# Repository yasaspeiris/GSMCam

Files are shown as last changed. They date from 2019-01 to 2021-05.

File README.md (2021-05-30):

# GSMCam
A Python program to determine the Grams per Square Meter of a Fabric using hardware accelerated Image Processing
(Also contains source code, design files and PCB schematics for cartesian slider system used to move the camera across fabrics.)

cover1_97ebsi5cop

Conventional method of fabric GSM measurement involves cutting a small round piece of fabric with an area of 0.01 square centimeters and measuring its weight using a precision balance.This project was aimed to replace this conventional method with an optical based one. Currently the scope of the project is limited to single light color (white) fabrics with a plain, twill weave. (Algorithm can also be applied to knit fabrics with a considerable accuracy as well)

For anyone looking to implement a hardware accelerated application with minimal development and debugging time, PYNQ is a great option. Currently PYNQ supports several boards including the Ultra96. The computer vision library for PYNQ provides several overlays for accelerating OpenCV functions in hardware. Currently Filter2D and dilation operations are supported. 

The following flow diagram depicts the stages in the GSM Determination process.

sssddd

The GUI is made using Flask, and can be used to calibrate and view results.



### Complete Instructions : 
https://www.hackster.io/yasaspeiris/fabric-gsm-determination-using-ultra96-pynq-6c5499

### Contributors : 

Pasindu Liyanage

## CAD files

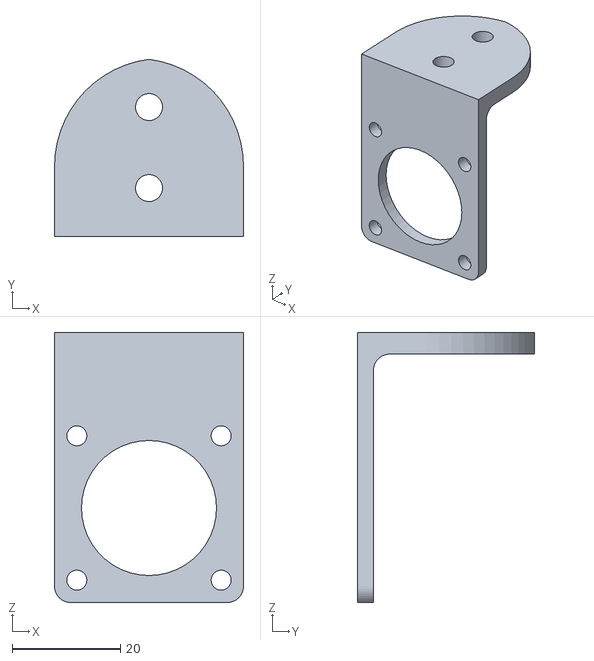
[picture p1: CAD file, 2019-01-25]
slider/slider_parts/ychainholder.STL
35.0 x 32.8 x 50.0

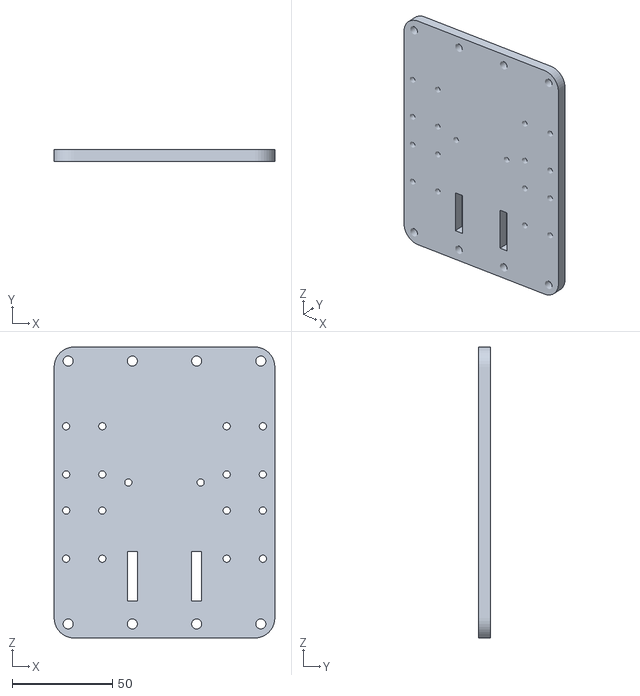
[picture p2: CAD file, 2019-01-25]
slider/slider_parts/ygantry.STL
110.0 x 6.00 x 145.0

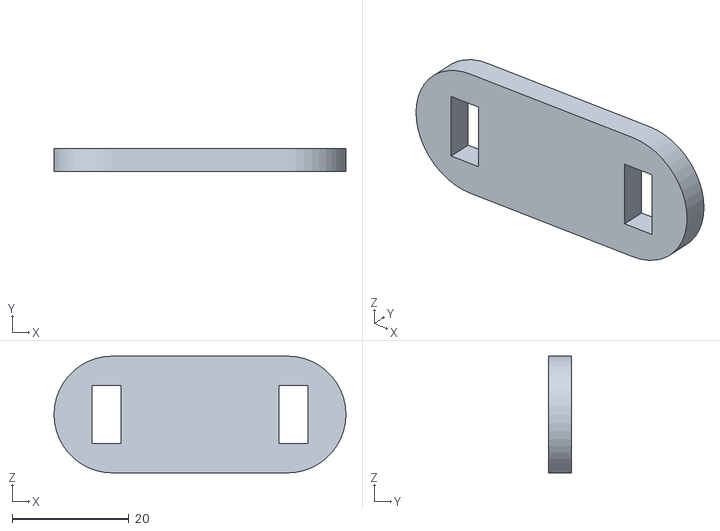
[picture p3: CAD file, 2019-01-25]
slider/slider_parts/zmotorspacer.STL
50.0 x 4.00 x 20.0

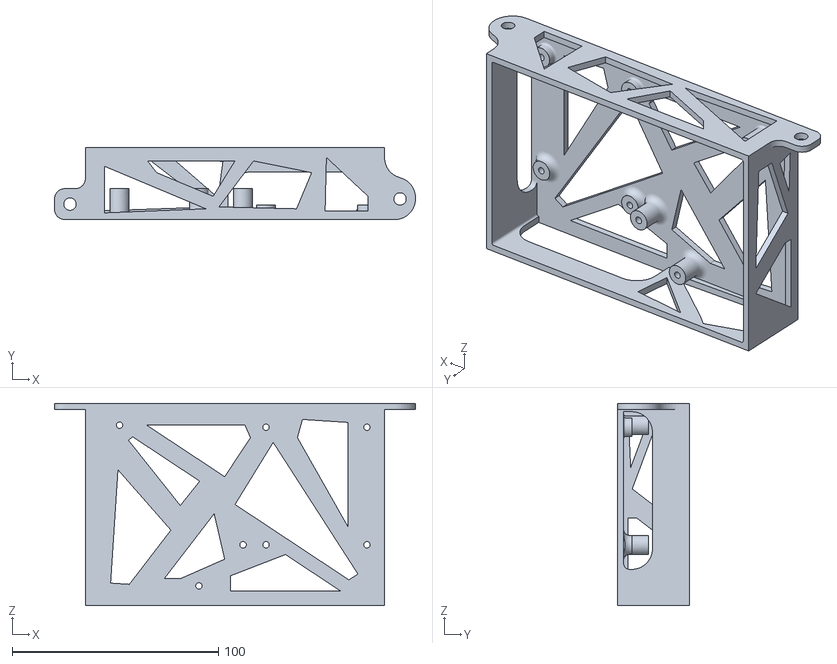
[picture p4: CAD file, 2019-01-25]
slider/slider_parts/cover.STL
175.0 x 35.0 x 98.0

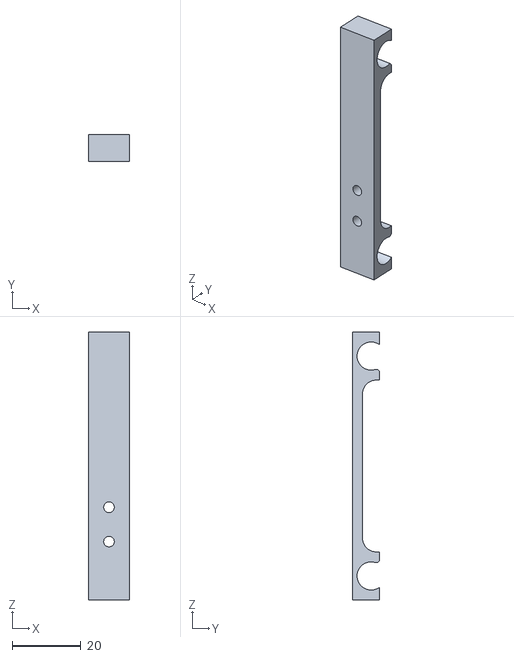
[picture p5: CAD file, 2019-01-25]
slider/slider_parts/switchholder_z.STL
12.0 x 8.00 x 78.0

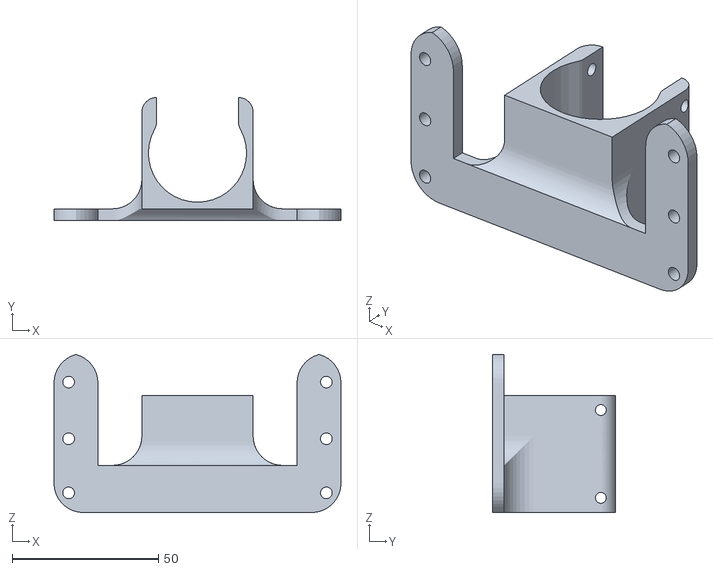
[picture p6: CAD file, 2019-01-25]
slider/slider_parts/camholder.STL
98.0 x 42.0 x 54.0

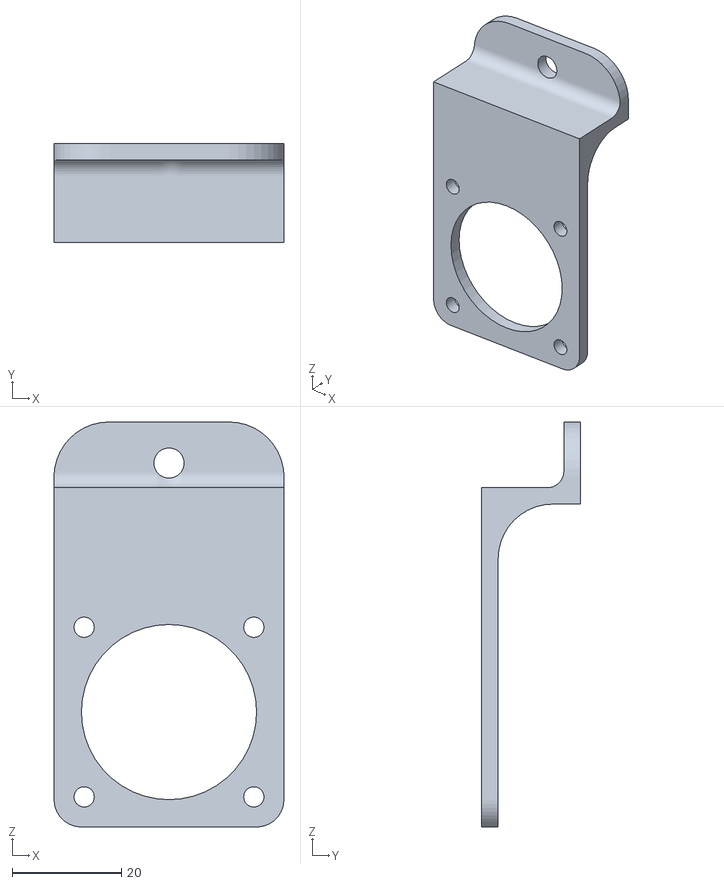
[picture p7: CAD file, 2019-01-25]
slider/slider_parts/chainsupportmotor.STL
42.0 x 18.0 x 74.0

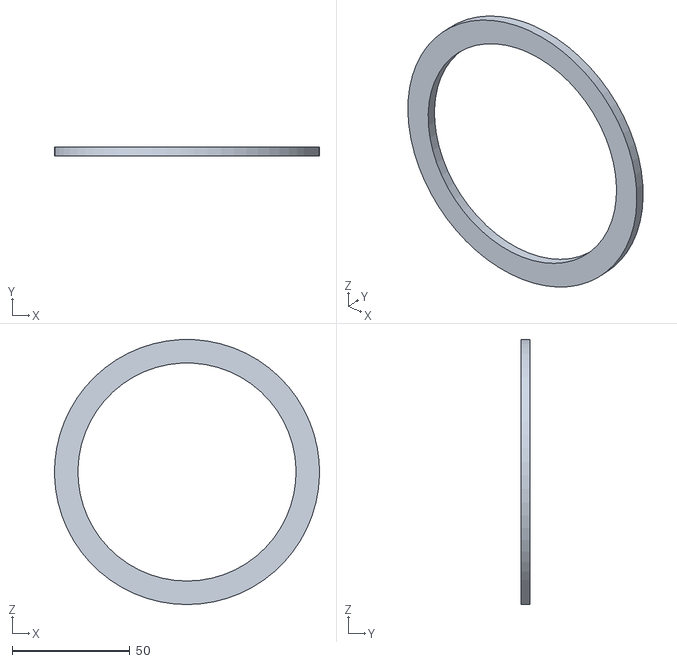
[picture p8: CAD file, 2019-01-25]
slider/slider_parts/fabriccutter.STL
112.8 x 4.00 x 112.8

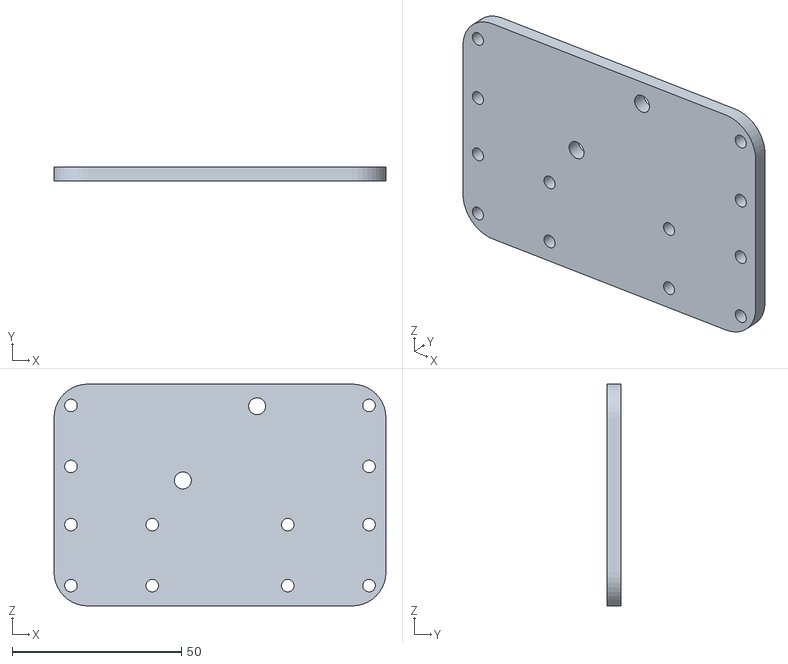
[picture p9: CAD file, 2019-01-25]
slider/slider_parts/zgantry.STL
98.0 x 4.00 x 65.5

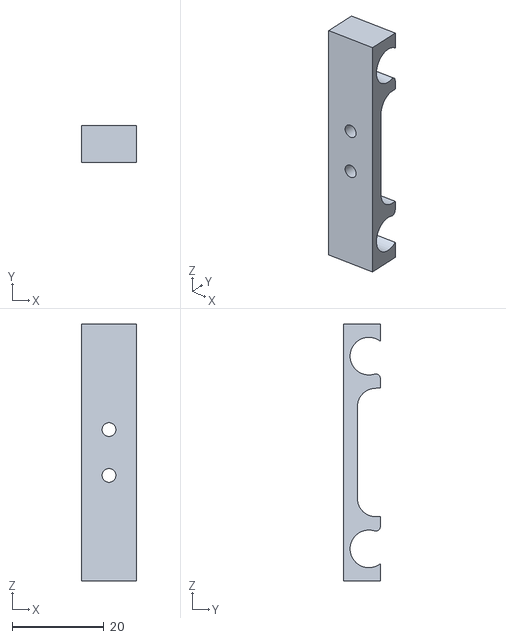
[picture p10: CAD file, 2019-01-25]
slider/slider_parts/switchhold.STL
12.0 x 8.00 x 56.0

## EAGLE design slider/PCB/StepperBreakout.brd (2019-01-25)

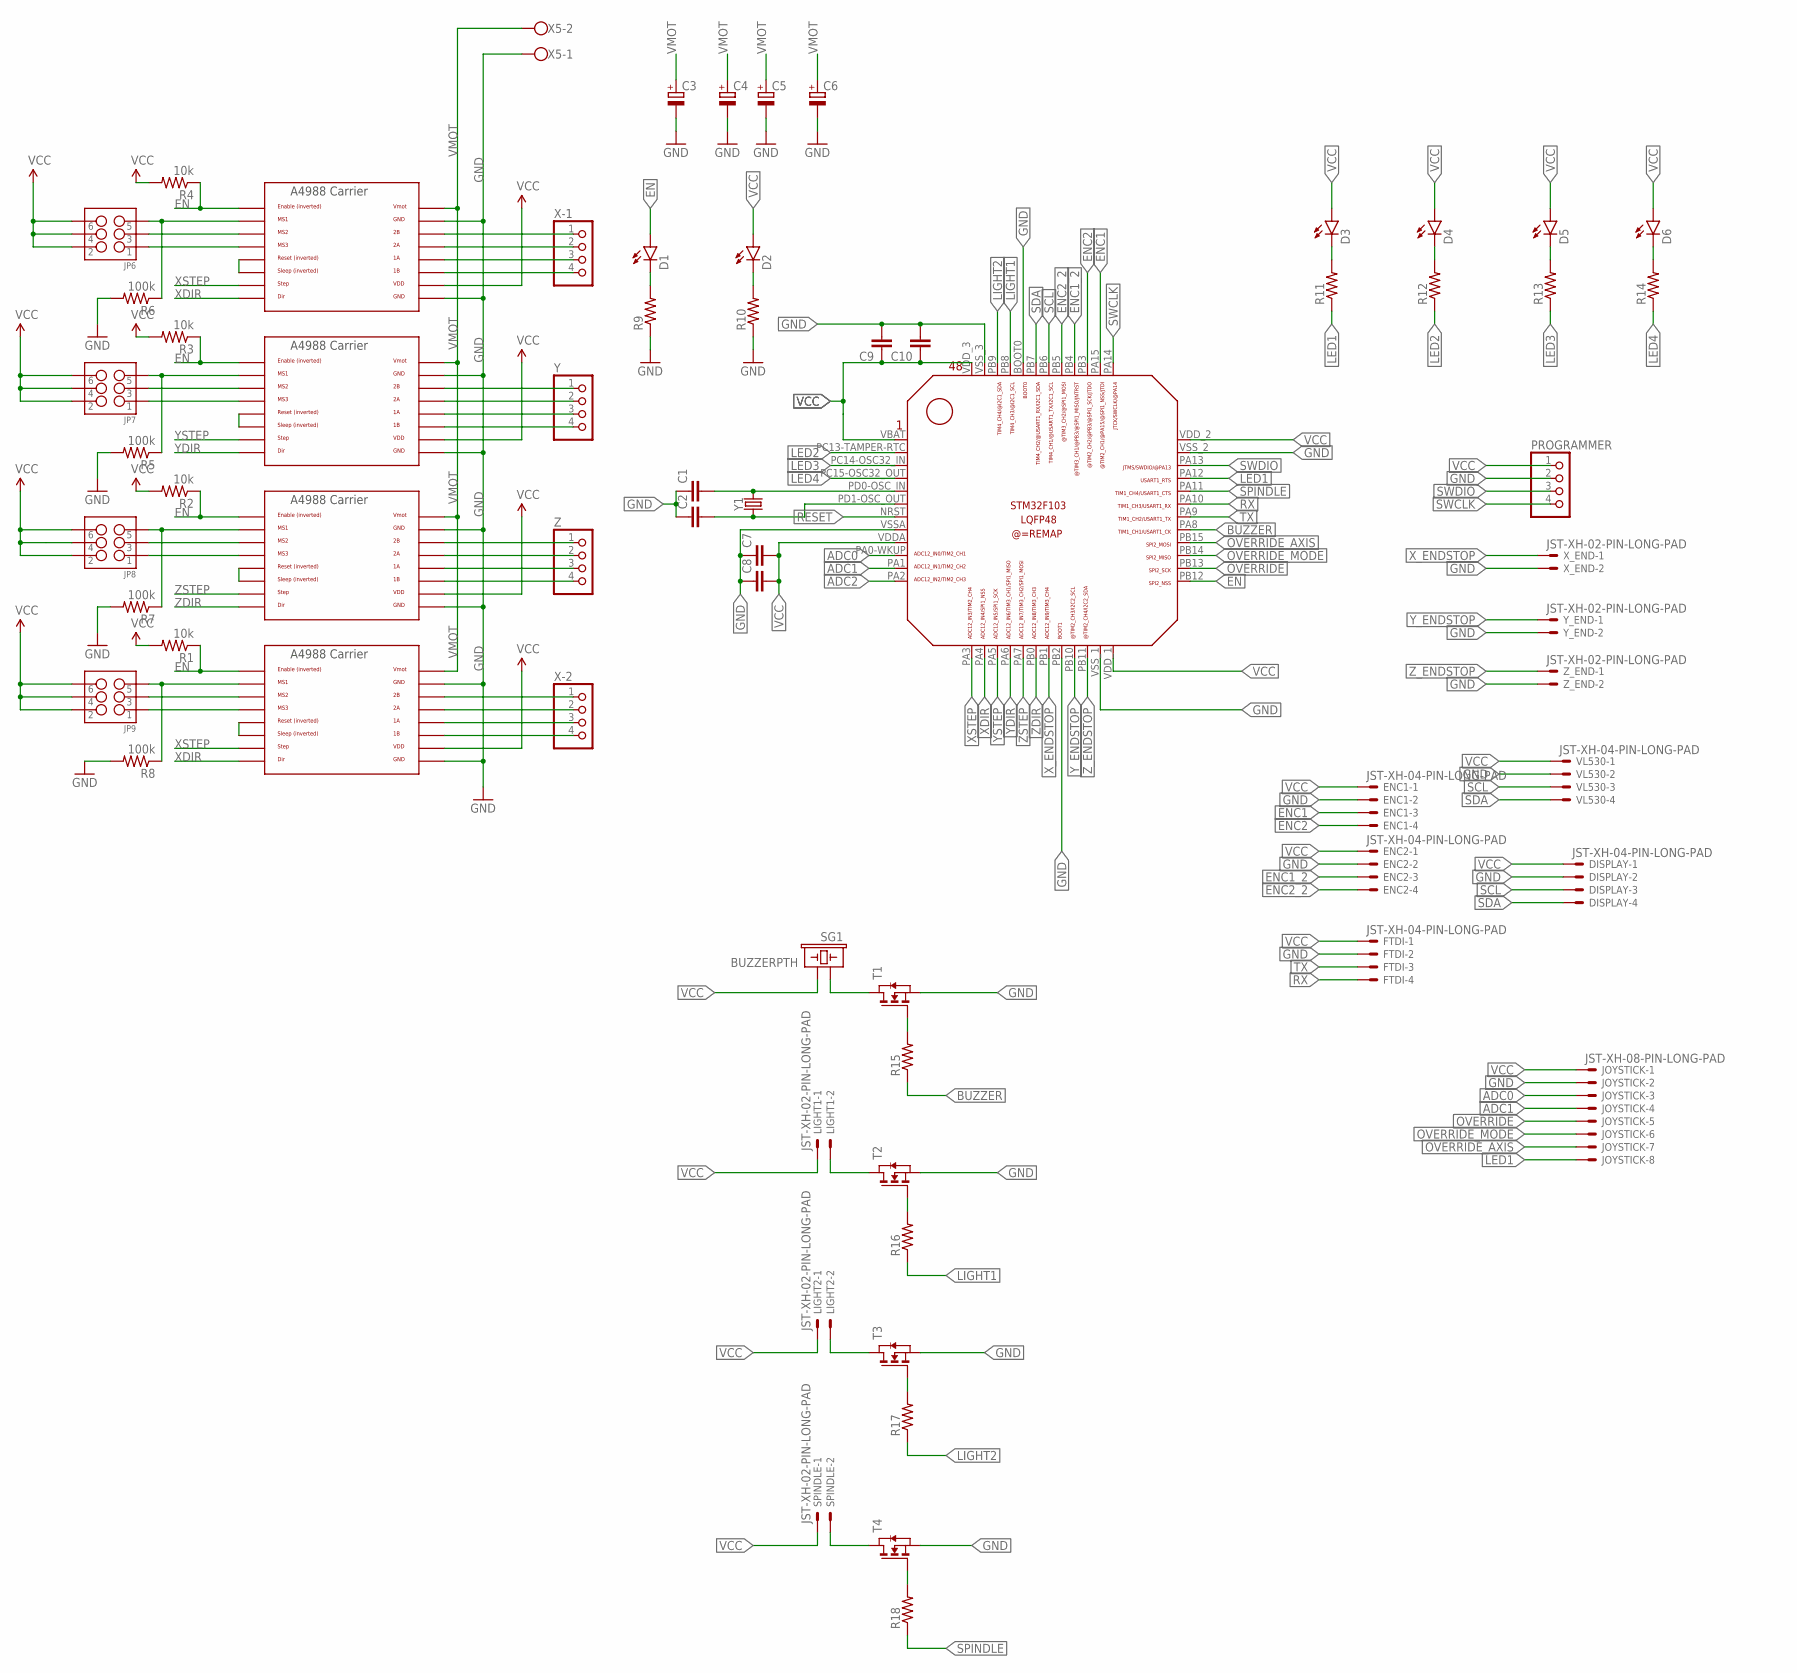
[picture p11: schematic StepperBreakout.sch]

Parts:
C1, C2, C7, C8, C9, C10: C-EUC0805; C0805
C3, C4, C5, C6: CPOL-EUE5-8.5; E5-8,5
D1, D2, D3, D4, D5, D6: LED0603; LED-0603
DISPLAY: JST-XH-04-PIN-LONG-PAD; JST-XH-04-PACKAGE-LONG-PAD
ENC1, ENC2: JST-XH-04-PIN-LONG-PAD; JST-XH-04-PACKAGE-LONG-PAD
FTDI: JST-XH-04-PIN-LONG-PAD; JST-XH-04-PACKAGE-LONG-PAD
JOYSTICK: JST-XH-08-PIN-LONG-PAD; JST-XH-08-PACKAGE-LONG-PAD
JP6, JP7, JP8, JP9: M03X2NO_SILK; 2X3-NS
LIGHT1, LIGHT2: JST-XH-02-PIN-LONG-PAD; JST-XH-02-PACKAGE-LONG-PAD
PROGRAMMER: PINHD-1X4; 1X04
R1, R2, R3, R4: 10k; 0805
R5, R6, R7, R8: 100k; 0805
R9, R10, R11, R12, R13, R14, R15, R16, R17, R18: RESISTOR0805-RES; 0805
SG1: BUZZERPTH; BUZZER-12MM
SPINDLE: JST-XH-02-PIN-LONG-PAD; JST-XH-02-PACKAGE-LONG-PAD
T1, T2, T3, T4: NMOSSOT23; SOT-23
U$1, U$2, U$3, U$4: POLOLU_A4983CARRIER; A4988BREAKOUT
U$5: STM32F103_LQFP48
VL530: JST-XH-04-PIN-LONG-PAD; JST-XH-04-PACKAGE-LONG-PAD
X5: W237-102
X-1, X-2: PINHD-1X4; 1X04
X_END: JST-XH-02-PIN-LONG-PAD; JST-XH-02-PACKAGE-LONG-PAD
Y: PINHD-1X4; 1X04
Y1: CRYSTALPTH-HC49UV; HC49U
Y_END: JST-XH-02-PIN-LONG-PAD; JST-XH-02-PACKAGE-LONG-PAD
Z: PINHD-1X4; 1X04
Z_END: JST-XH-02-PIN-LONG-PAD; JST-XH-02-PACKAGE-LONG-PAD

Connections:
ADC0: JOYSTICK.3, U$5.PA0-WKUP
ADC1: JOYSTICK.4, U$5.PA1
ADC2: U$5.PA2
BUZZER: R15.1, U$5.PA8
EN: D1.A, R1.1, R2.1, R3.1, R4.1, U$1.EN, U$2.EN, U$3.EN, U$4.EN, U$5.PB12
ENC1: ENC1.3, U$5.PA15
ENC1_2: ENC2.3, U$5.PB4
ENC2: ENC1.4, U$5.PB3
ENC2_2: ENC2.4, U$5.PB5
GND: C1.1, C2.1, C3.-, C4.-, C5.-, C6.-, C7.1, C8.1, C9.2, C10.2, DISPLAY.2, ENC1.2, ENC2.2, FTDI.2, JOYSTICK.2, PROGRAMMER.2, R5.2, R6.2, R7.2, R8.2, R9.1, R10.1, T1.2 (S), T2.2 (S), T3.2 (S), T4.2 (S), U$1.GND, U$1.GND@0 (GND), U$2.GND, U$2.GND@0 (GND), U$3.GND, U$3.GND@0 (GND), U$4.GND, U$4.GND@0 (GND), U$5.BOOT0, U$5.PB2, U$5.VSSA, U$5.VSS_1, U$5.VSS_2, U$5.VSS_3, VL530.2, X5.1, X_END.2, Y_END.2, Z_END.2
LED1: JOYSTICK.8, R11.1, U$5.PA12
LED2: R12.1, U$5.PC13-TAMPER-RTC
LED3: R13.1, U$5.PC14-OSC32_IN
LED4: R14.1, U$5.PC15-OSC32_OUT (PC15-OSC_OUT)
LIGHT1: R16.1, U$5.PB8
LIGHT2: R17.1, U$5.PB9
unnamed: U$3.1B, Y.4
unnamed: U$3.1A, Y.3
unnamed: U$3.2A, Y.2
unnamed: U$3.2B, Y.1
unnamed: U$1.2B, Z.1
unnamed: U$1.2A, Z.2
unnamed: U$1.1A, Z.3
unnamed: U$1.1B, Z.4
unnamed: U$2.2B, X-2.1
unnamed: U$2.2A, X-2.2
unnamed: U$2.1A, X-2.3
unnamed: U$2.1B, X-2.4
unnamed: U$4.2B, X-1.1
unnamed: U$4.2A, X-1.2
unnamed: U$4.1A, X-1.3
unnamed: U$4.1B, X-1.4
unnamed: JP6.5, R6.1, U$4.MS1
unnamed: JP6.3, U$4.MS2
unnamed: JP6.1, U$4.MS3
unnamed: JP7.5, R5.1, U$3.MS1
unnamed: JP7.3, U$3.MS2
unnamed: JP7.1, U$3.MS3
unnamed: JP8.5, R7.1, U$1.MS1
unnamed: JP8.3, U$1.MS2
unnamed: JP8.1, U$1.MS3
unnamed: JP9.5, R8.1, U$2.MS1
unnamed: JP9.3, U$2.MS2
unnamed: JP9.1, U$2.MS3
unnamed: C1.2, U$5.PD0-OSC_IN, Y1.2
unnamed: D1.C, R9.2
unnamed: D2.C, R10.2
unnamed: C2.2, U$5.PD1-OSC_OUT, Y1.1
unnamed: U$2.RST, U$2.SLP (SLEEP)
unnamed: U$1.RST, U$1.SLP (SLEEP)
unnamed: U$3.RST, U$3.SLP (SLEEP)
unnamed: U$4.RST, U$4.SLP (SLEEP)
unnamed: D3.C, R11.2
unnamed: D4.C, R12.2
unnamed: D5.C, R13.2
unnamed: D6.C, R14.2
unnamed: SG1.+ (1), T1.1 (D)
unnamed: R15.2, T1.3 (G)
unnamed: LIGHT1.2, T2.1 (D)
unnamed: R16.2, T2.3 (G)
unnamed: LIGHT2.2, T3.1 (D)
unnamed: R17.2, T3.3 (G)
unnamed: SPINDLE.2, T4.1 (D)
unnamed: R18.2, T4.3 (G)
OVERRIDE: JOYSTICK.5, U$5.PB13
OVERRIDE_AXIS: JOYSTICK.7, U$5.PB15
OVERRIDE_MODE: JOYSTICK.6, U$5.PB14
RESET: U$5.NRST
RX: FTDI.4, U$5.PA10
SCL: DISPLAY.3, U$5.PB6, VL530.3
SDA: DISPLAY.4, U$5.PB7, VL530.4
SPINDLE: R18.1, U$5.PA11
SWCLK: PROGRAMMER.4, U$5.PA14
SWDIO: PROGRAMMER.3, U$5.PA13
TX: FTDI.3, U$5.PA9
VCC: C7.2, C8.2, C9.1, C10.1, D2.A, D3.A, D4.A, D5.A, D6.A, DISPLAY.1, ENC1.1, ENC2.1, FTDI.1, JOYSTICK.1, JP6.2, JP6.4, JP6.6, JP7.2, JP7.4, JP7.6, JP8.2, JP8.4, JP8.6, JP9.2, JP9.4, JP9.6, LIGHT1.1, LIGHT2.1, PROGRAMMER.1, R1.2, R2.2, R3.2, R4.2, SG1.- (2), SPINDLE.1, U$1.VDD, U$2.VDD, U$3.VDD, U$4.VDD, U$5.VBAT, U$5.VDDA, U$5.VDD_1, U$5.VDD_2, U$5.VDD_3, VL530.1
VMOT: C3.+, C4.+, C5.+, C6.+, U$1.VMOT, U$2.VMOT, U$3.VMOT, U$4.VMOT, X5.2
XDIR: U$2.DIR, U$4.DIR, U$5.PA4
XSTEP: U$2.STEP, U$4.STEP, U$5.PA3
X_ENDSTOP: U$5.PB1, X_END.1
YDIR: U$3.DIR, U$5.PA6
YSTEP: U$3.STEP, U$5.PA5
Y_ENDSTOP: U$5.PB10, Y_END.1
ZDIR: U$1.DIR, U$5.PB0
ZSTEP: U$1.STEP, U$5.PA7
Z_ENDSTOP: U$5.PB11, Z_END.1

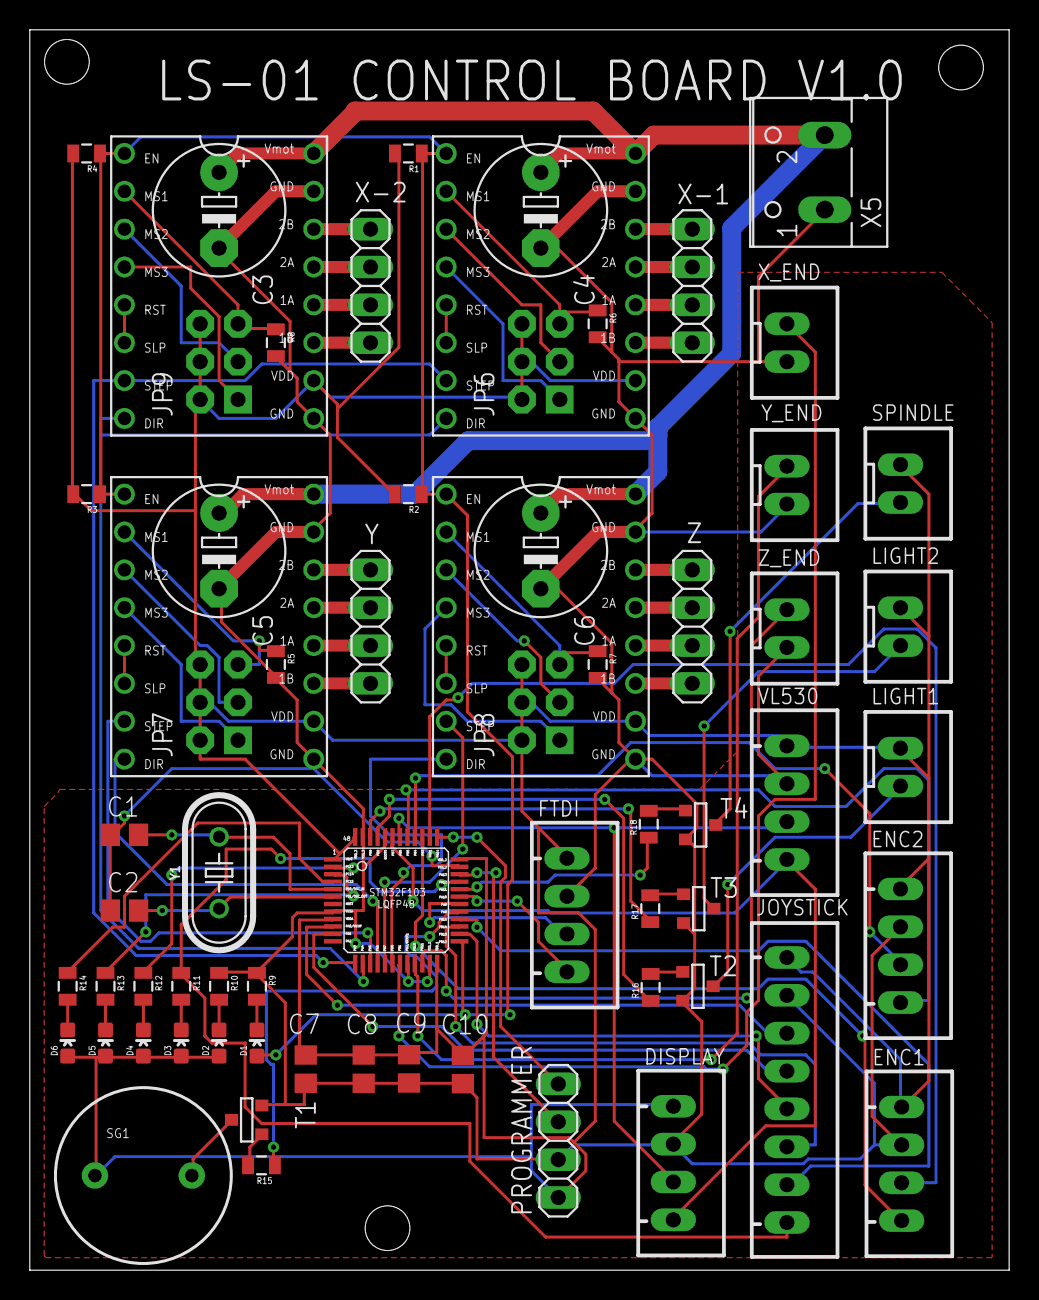
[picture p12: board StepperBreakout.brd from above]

Board: 2 copper layers, 65.7 x 83.2 mm, 67 parts (0 on the bottom side), 84 nets.

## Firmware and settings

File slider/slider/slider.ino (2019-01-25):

//Limit Switches
#define XLIMIT PB1 //Limit switches must be Normally Open and connected to GND.
#define YLIMIT PB10
#define ZLIMIT PB11

#define XSTEP PA3
#define XDIR PA4

#define YSTEP PA5
#define YDIR PA6

#define ZSTEP PA7
#define ZDIR PB0

#define ENABLE PB12

#define XMOTORACC 500
#define XMOTORMAXSPEED 800

#define YMOTORACC 1000
#define YMOTORMAXSPEED 1000

#define ZMOTORACC 1000
#define ZMOTORMAXSPEED 1000

#define X_PER_MM 5
#define Y_PER_MM 5
#define Z_PER_MM 100

#define X_MAX 200
#define Y_MAX 200
#define Z_MAX 400

#include <AccelStepper.h>

AccelStepper XMOTOR(1,XSTEP,XDIR);
AccelStepper YMOTOR(1,YSTEP,YDIR);
AccelStepper ZMOTOR(1,ZSTEP,ZDIR);


//=====[ CONSTANTS ]============================================================
#define   DEBUG   0   // 0 = debugging disabled, 1 = enabled
#define ENABLE_ACTUATORS 1 //Set to one to make steppers move according to serial input

//=====[ VARIABLES ]============================================================

String readString; //main captured String 
int Xval = 0; //Absolute positions of X,Y,Z. 
int Yval = 0;
int Zval = 0;
int func = 0;

int ind1; // , location indexes for serial parse
int ind2;
int ind3;
int ind4;

void setup() {
  // put your setup code here, to run once:
  Serial1.begin(9600);
  Serial1.setTimeout(1);
  pinsetup();
  for (int i = 0; i<5; i++){
    tone(PA8, 31, 300);
    delay(200);
    tone(PA8, 61, 300);
    delay(200);
  }
  
  delay(2000);
  autohome(); //I've disabled autohome for now.

}

void loop() {
  //=====[ IMPORTANT ]============================================================
  //Your input string must use , as the data delimiter and * as the line delimeter. Eg - to move X to 2 Y to 5 and Z to 10 and grabber to 20, you should send   2,5,10,20*
  //You can see if its correct by setting DEBUG to 1 and looking at the output.
  //Set ENABLE_ACTUATORS to enable movement of steppers.
  //Once you're sure about the movement and directions, test autohome function.
  SerialParser();

  
}

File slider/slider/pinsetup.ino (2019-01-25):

void pinsetup() {
  pinMode(XLIMIT, INPUT_PULLUP);
  pinMode(YLIMIT, INPUT_PULLUP);
  pinMode(ZLIMIT, INPUT_PULLUP);

  pinMode(ENABLE,OUTPUT);
  digitalWrite(ENABLE,LOW);

}

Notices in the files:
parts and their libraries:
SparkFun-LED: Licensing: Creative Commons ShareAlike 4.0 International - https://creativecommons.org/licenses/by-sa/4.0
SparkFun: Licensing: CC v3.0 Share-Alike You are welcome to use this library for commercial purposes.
